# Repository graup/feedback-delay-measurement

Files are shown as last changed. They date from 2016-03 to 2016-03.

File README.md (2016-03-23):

# Feedback Delay Measurement Instrument

This repository holds all source code and design files for my bachelor thesis: "Development and Evaluation of an Arduino-based Feedback Delay Measurement Instrument" (Paul Grau, 2016)

## Contents

* [Thesis full text](http://graycoding.com/publications/2016_BA_Thesis.pdf) (PDF)
* [PCB layout](./pcb/) (Eagle schematic and board)
* [Measurement program](./arduino/measure.ino) (Arduino sketch)
* [How to](./HOWTO.md)

## See also
* [Author's homepage](http://graycoding.com/publications/)

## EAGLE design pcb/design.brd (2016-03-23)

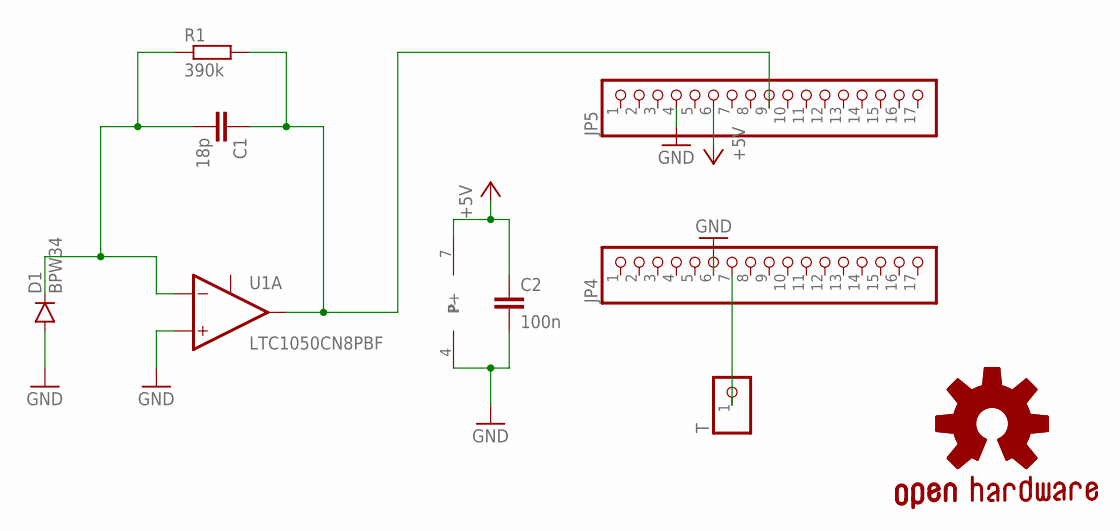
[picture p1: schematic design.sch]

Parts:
C1: 18p; C025-025X050
C2: 100n; C025-025X050
D1: BPW34
GOLD_ORB_SM1: OSHWLOGO_GOLD_ORB_SM; OSHW2
JP4, JP5: PINHD-1X17; 1X17
R1: 390k; 0207/2V
T: PINHD-1X1; 1X01
U1: LTC1050CN8PBF; DIP254P762X508-8

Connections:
+5V: C2.1, JP5.6, U1.7 (P+)
GND: C2.2, D1.P$1 (A), JP4.6, JP5.4, U1.3 (IN+), U1.4 (P-)
unnamed: C1.2, D1.P$2 (C), R1.1, U1.2 (IN-)
unnamed: C1.1, JP5.9, R1.2, U1.6 (OUT)
unnamed: JP4.7, T.1

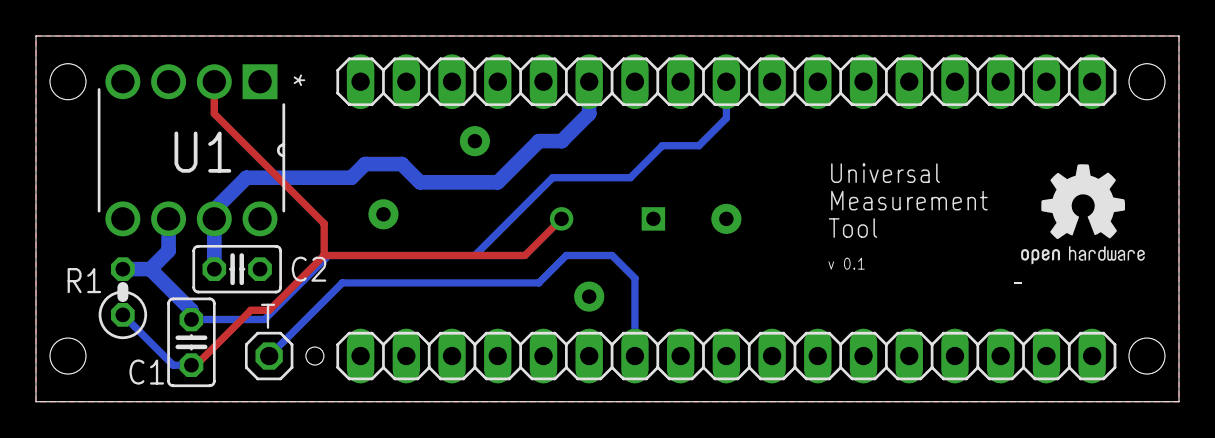
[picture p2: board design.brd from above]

Board: 2 copper layers, 63.5 x 20.3 mm, 9 parts (1 on the bottom side), 5 nets.

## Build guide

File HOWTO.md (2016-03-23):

# How to use

1. Assemble hardware
  - You need the printed circuit board and a few parts. You can also put everything together on a breadboard if you don't like soldering.
  - Parts needed: Arduino Micro, LTC1050, BPW45, capacitor 10nF and 15pF, resistor 380 kOhm.

2. Connect Arduino via USB. Open the program code in the Arduino IDE. Have a look at the file, it has some additional explanations and settings.

3. Place the board onto the screen you want to measure. Connect the trigger pin to the touch screen if you want to use it.

4. Upload the sketch to the Arduino. Follow the program instructions.

5. When everything is set up and tested, start the measurement. Use the Arduino Serial Monitor to get the results. The Arduino will print one measurement per line via Serial.

6. Put the numbers into your favorite statistics software.

# Any questions?

Everything is explained in detail in my thesis, but please don't hesitate to contact me with any further questions!

[Paul Grau](http://graycoding.com), March 2016

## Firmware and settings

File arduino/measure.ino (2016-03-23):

/**
 * Feedback Delay measurement program
 * 
 * How to use:
 * - Connect all components to the Arduino
 * - Connect the Arduino to the PC
 * - Connect the smartphone to the same ground as the measuring device
 * - Upload the sketch to the Arduino
 * - Open the Serial Monitor
 * - It will run a self test, triggering on and off
 * - As soon as the trigger starts working reliably, send anything over the Serial connection
 *   (i.e. type any character into the Serial Monitor input box and hit Send)
 * - The measurement routine will start
 * - Every measurement's result, the delay in nanoseconds, will be printed on one line.
 *
 * Author: Paul Grau <paul@graycoding.com>, 2016
 */
#include "pins_arduino.h"
#include <Mouse.h>
 
const short PIN_PHOTOCELL = A5;
const short PIN_LED = LED_BUILTIN;
const short PIN_TRIGGER = 2;
const short TRIGGER_MODE = 1; // 0 = Mouse click, 1 = pull PIN_TRIGGER to ground

long aval = 0; // Last analog value reading
unsigned long mean = 0; // Rolling mean
unsigned long meansq = 0; // Rolling mean square
unsigned int variance; // Current variance
const short variance_threshold = 6000; // Threshold to detect change
boolean detected_change = false;

void setup() {
  pinMode(PIN_LED, OUTPUT);

  // Setup ADC interrupts
  DIDR0 = 0x3F; // disbale digital inputs on analog pins
  ADMUX = (INTERNAL << 6) | (analogPinToChannel(PIN_PHOTOCELL-18) & 0x07); // select reference and input
  ADCSRA = 0xA8 | 0b111; // ADC, interrupt enabled, prescaler = 128
  ADCSRB = 0x40; // AD channels MUX on, free running mode
  bitWrite(ADCSRA, 6, 1); // Start the conversion by setting bit 6 (ADSC)
  sei(); // enable interrupts
  
  Serial.begin(115200);
  while (!Serial); // Wait for serial connection before resuming

  if (TRIGGER_MODE == 1) {
    // Trigger input a few times
    Serial.print("Self test: touch trigger on Pin ");
    Serial.println(PIN_TRIGGER);
    Serial.println("Send anything over Serial to device as soon as touches are triggered.");
    
    while(1) {
      trigger_input(true);
      digitalWrite(PIN_LED, HIGH); // LED on
      delay(400);
      trigger_input(false);   
      digitalWrite(PIN_LED, LOW); // LED off 
      delay(400);
      
      if (Serial.available() > 0) break;
    }
  }

  if (TRIGGER_MODE == 0) {
    Serial.println("Device acts as a HID now!");
    Serial.println("To stop, just disconnect USB.");
    Mouse.begin();
  }

  // Test photo diode
  Serial.print("Make sure photodiode is connected to PIN A");
  Serial.println(PIN_PHOTOCELL-18);
  delay(500);
}

/**
 * Interrupt routine for ADC ready 
 */
ISR(ADC_vect) {
  aval = ADCL;        // store lower byte ADC
  aval += ADCH << 8;  // store higher bytes ADC
  update_stats();
}

/**
 * Update statistical values
 */
void update_stats() {
  unsigned long aval_shifted = aval + 500;
  mean = mean*0.75 + (aval_shifted >> 2);
  meansq = meansq*0.75 + ((aval_shifted*aval_shifted) >> 2);
  variance = meansq - mean*mean;
  detected_change = detected_change || detect_change();
}

/**
 * Detect a change when variance exceeds threshold
 */
int detect_change() {
  return (variance > variance_threshold);
}

/**
 * Trigger an input event
 */
void trigger_input(boolean on) {
  // Touch trigger
  if (TRIGGER_MODE == 1) {
    if (on) {
       pinMode(PIN_TRIGGER, OUTPUT);
       digitalWrite(PIN_TRIGGER, LOW); // touch
    } else {
       pinMode(PIN_TRIGGER, INPUT); // touch up
    }
  }
  // USB Mouse trigger
  if (TRIGGER_MODE == 0) {
    if (on) {
      Mouse.press();
    } else {
      Mouse.release();
    }
  }
}

/**
 * Measurement routine
 */
void measure() {
  delay(400); // Wait a few samples to recalibrate mean

  // Start measurement
  detected_change = false;
  digitalWrite(PIN_LED, HIGH); // LED on
  trigger_input(true);
  unsigned long measure_start = micros();
  
  while (!detected_change) {
    // Keep sampling until threshold is reached
    delayMicroseconds(1);
  }

  // Stop measurement
  unsigned long measure_duration = micros() - measure_start;
  digitalWrite(PIN_LED, LOW); // LED off
  Serial.println(measure_duration);
  trigger_input(false);
}

void loop() {
  measure();
}

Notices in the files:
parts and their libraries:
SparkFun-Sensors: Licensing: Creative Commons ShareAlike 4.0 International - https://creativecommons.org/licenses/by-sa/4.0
